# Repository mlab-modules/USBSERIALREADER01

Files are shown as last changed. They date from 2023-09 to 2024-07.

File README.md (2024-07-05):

# USBSDREADER01 - USB to SD Card Reader Module

## Overview
This module is designed to interface USB devices with SD cards, utilizing the MAX14502AETL integrated circuit. The MAX14502AETL supports both full-speed USB communication (12Mbps) for bridget devices and Hi-Speed USB communication (480Mbps) as SDcard reader, providing a versatile solution for various USB to SD card reading applications.

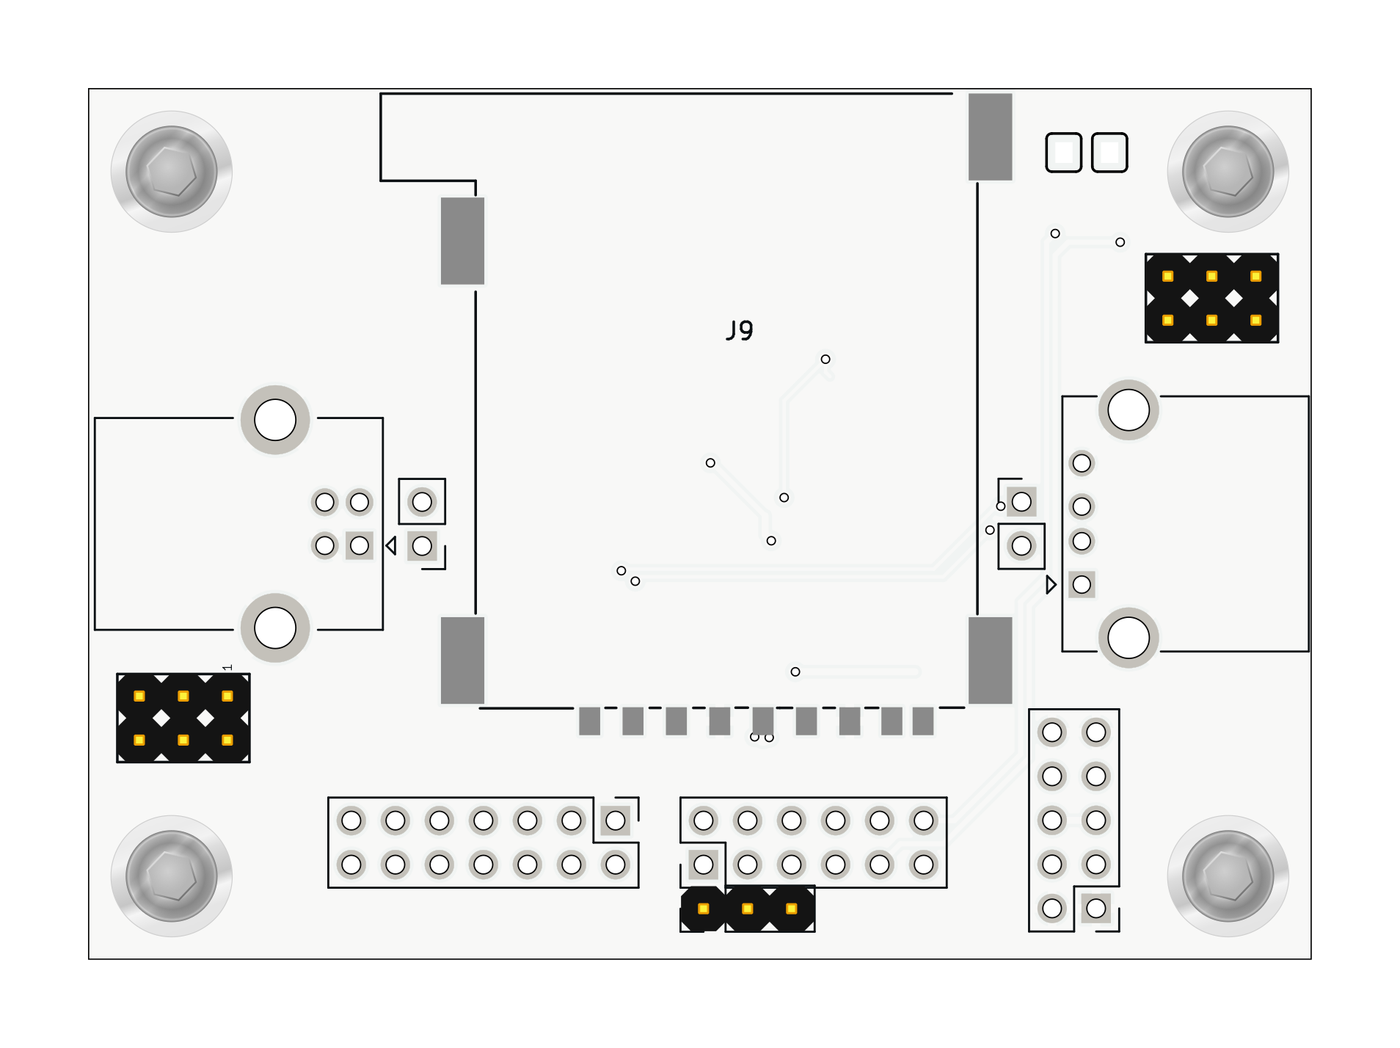
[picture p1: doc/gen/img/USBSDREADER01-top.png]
USBSDREADER01

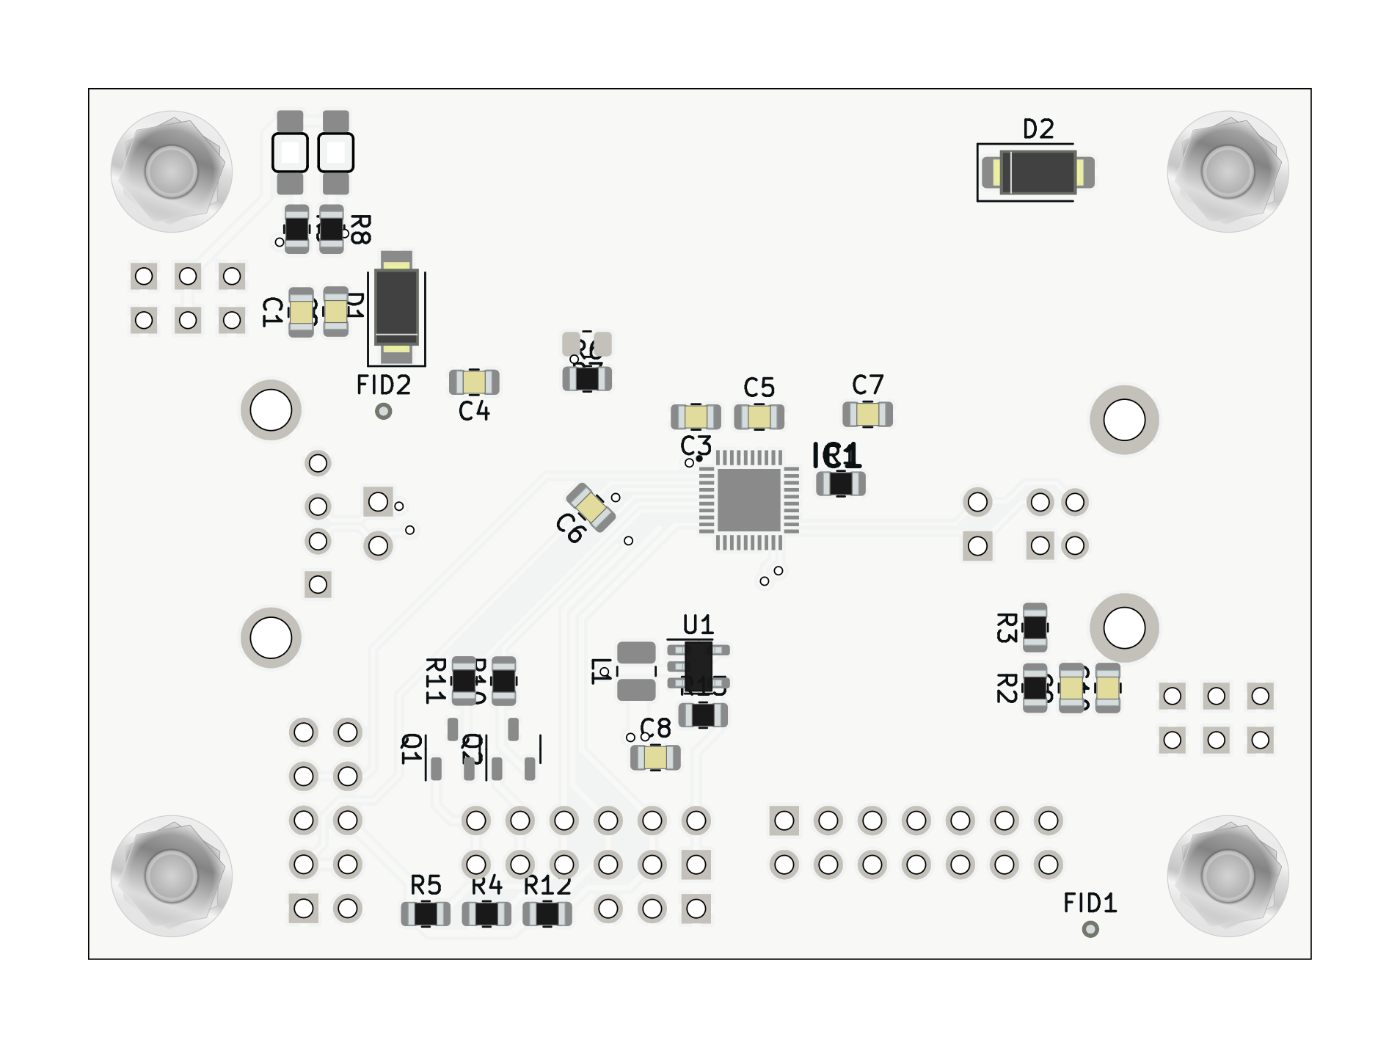
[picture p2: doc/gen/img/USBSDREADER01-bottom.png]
USBSDREADER01


## Features
- **USB 2.0 Hi-Speed and Full-Speed Compliant**
- **Supports SDHC Cards**
- **Internal Hi-Speed USB SD Card Reader**
- **On-Chip Termination and Pullup Resistors**
- **Internal SD Switches for Multiplexing Two SD Cards**
- **Clock Input Frequencies: 26MHz, 19.2MHz, 13MHz, 12MHz**
- **Low-Amplitude TCXO Signal Compatibility**
- **No Power-Supply Sequencing Required**
- **1.8V to 3.3V I/O Host Microprocessor Compatibility**
- **Simple GPIO Control Mode**
- **I2C Control for Multiple Configuration Options**
- **Power-On Reset/Brown-Out Reset**

## Technical Specifications
- **Supply Voltage (VCC):** 2.4V to 3.6V
- **Logic Interface Supply Voltage (VIO):** 1.5V to 3.6V
- **USB Supply Voltage (VTM):** 2.91V to 3.4V
- **Operating Temperature Range:** -40°C to +85°C
- **Package:** 40-pin TQFN

## Pin Description
- **I2C_SEL:** I2C Select Input
- **SCL:** I2C Serial-Clock Input
- **SDA:** I2C Serial-Data I/O
- **ADD:** I2C Address Selection Input
- **BERR/INT:** Card Reader Error/Interrupt Output
- **BUSY:** Busy Output
- **MODE:** Card Reader/Pass Thru Mode Select Input
- **RST:** Reset Input
- **FREF:** Frequency Input (12MHz/13MHz/19.2MHz/26MHz)

## Schematic
USB to SD Card Reader Schematic

## Applications
- Data loggers
- Cameras
- Flight computers

## Installation and Usage
1. **Power Supply:**
   - Connect the power supply to the VCC and GND pins.
   - Ensure the supply voltage is within the specified range (2.4V to 3.6V).

2. **USB Connection:**
   - Connect the USB data lines (D+ and D-) to the corresponding pins on the module.
   - Use the USB_B and USB_A connectors for input and output respectively.

3. **SD Card Connection:**
   - Connect the SD card signals (CMD, CLK, DAT0-3) to the corresponding pins on the module.
   - Ensure proper insertion and alignment of the SD card.

4. **I2C Configuration:**
   - If I2C control is needed, connect the I2C_SEL, SCL, and SDA pins appropriately.
   - Configure the I2C address using the ADD pin.

5. **Operation Modes:**
   - Select Pass Thru or Card Reader mode using the MODE pin.
   - Reset the device using the RST pin if necessary.

For detailed electrical characteristics and operational guidance, refer to the [MAX14502AETL Datasheet](./doc/datasheet/Maxim_Integrated-MAX14502AETL+-datasheet.pdf).

## Support
For further assistance, visit [MLAB](https://www.mlab.cz/) or contact our support team at support@mlab.cz.

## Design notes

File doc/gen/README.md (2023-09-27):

# PCB

Board size: 70.61x50.29 mm (2.78x1.98 inches)

- This is the size of the rectangle that contains the board
- Thickness: 1.6 mm (63 mils)
- Material: FR4
- Finish: HAL
- Layers: 2
- Copper thickness: 35 µm

Solder mask: TOP / BOTTOM

- Color: Green

Silk screen: TOP / BOTTOM

- Color: White

# Important sizes

Clearance: 0.2 mm (8 mils)

Track width: 0.2 mm (8 mils)

- By design rules: 0.2 mm (8 mils)

Drill: 0.5 mm (20 mils)

- Vias: 0.5 mm (20 mils) [Design: 0.4 mm (16 mils)]
- Pads: 1.0 mm (39 mils)
- The above values are real drill sizes, they add 0.1 mm (4 mils) to plated holes (PTH)

Via: 0.8/0.4 mm (31/16 mils)

- By design rules: 0.4/0.3 mm (16/12 mils)
- Micro via: yes [0.2/0.1 mm (8/4 mils)]
- Buried/blind via: yes
- Total: 13 (thru: 13 buried/blind: 0 micro: 0)

Outer Annular Ring: 0.15 mm (6 mils)

- By design rules: 0.26 mm (10 mils)

Eurocircuits class: 4B
- Using min drill 0.5 mm for an OAR of 0.15 mm

# General stats

Components count: (SMD/THT)

- Top: 1/14 (SMD + THT)
- Bottom: 34/0 (SMD)

Defined tracks:

- 0.2 mm (8 mils)
- 0.3 mm (12 mils)
- 0.4 mm (16 mils)
- 0.5 mm (20 mils)
- 1.0 mm (39 mils)

Used tracks:

- 0.2 mm (8 mils) (82) defined: yes
- 0.3 mm (12 mils) (62) defined: yes
- 0.4 mm (16 mils) (34) defined: yes
- 1.0 mm (39 mils) (4) defined: yes

Defined vias:

Used vias:

- 0.8/0.4 mm (31/16 mils) (Count: 13, Aspect: 2.0 A) defined: no

Holes (excluding vias):

- 0.89 mm (35 mils) (12)
- 0.92 mm (36 mils) (4)
- 0.95 mm (37 mils) (4)
- 1.0 mm (39 mils) (43)
- 2.3 mm (91 mils) (4)
- 3.0 mm (118 mils) (4)

Oval holes:

Drill tools (including vias and computing adjusts and rounding):

- 0.5 mm (20 mils) (13)
- 1.0 mm (39 mils) (16)
- 1.05 mm (41 mils) (4)
- 1.1 mm (43 mils) (43)
- 2.4 mm (94 mils) (4)
- 3.1 mm (122 mils) (4)

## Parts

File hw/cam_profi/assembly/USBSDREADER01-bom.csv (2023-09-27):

Component | Description | Part | References | Value | Footprint | Quantity Per PCB | Datasheet | ust_id | height | manufacturer_name | manufacturer_part_number | sim.device | sim.pins | sim.type
1 |  | C_Small-Device-ISM02A-rescue | C2C10 | 100nF | C_0805_2012Metric | 2 |  | 5c70984812875079b91f8bf2
2 |  | C_Small-Device-ISM02A-rescue | C1C9 | 10uF | C_0805_2012Metric | 2 |  | 5c70984812875079b91f8bbe
3 | Unpolarized capacitor, small symbol | C_Small | C8 | 10uF | C_0805_2012Metric | 1 | ~
4 | Unpolarized capacitor, small symbol | C_Small | C3C4C5C6C7 | C_Small | C_0805_2012Metric | 5 | ~
5 |  | D_ZENER-MLAB_D | D1D2 | BZV55C-5,6V | D_SMA | 2 |  | 5c70984512875079b91f88b2
6 | Light emitting diode | LED | D3D4 | LED | LED_1206_mill | 2 | ~
7 | Hi-Speed USB-to-SD Card Readers with Bypass | MAX14502AETL+ | IC1 | MAX14502AETL+ | QFN40P500X500X80-41N | 1 | https://datasheet.octopart.com/MAX14502AETL%2B-Dallas-Semiconductor-datasheet-13718882.pdf |  | 0.8 | Analog Devices | MAX14502AETL+
8 | 2x03 2.54 mm pitch header, 2 pins next to each other are connected | HEADER_2x03_PARALLEL | J1 | 3.3V | Straight_2x03 | 1
9 | 1x03 2.54 mm pitch header | HEADER_1x03 | J8 | HEADER_1x02 | PinHeader_1x03_P2.54mm_Vertical | 1
10 | 2x06 2.54 mm pitch header, 2 pins next to each other are connected | HEADER_2x06_PARALLEL | J7 | HEADER_2x04_PARALLEL | PinHeader_2x06_P2.54mm_Vertical | 1
11 | 2x05 2.54 mm pitch header, 2 pins next to each other are connected | HEADER_2x05_PARALLEL | J6 | HEADER_2x05_PARALLEL | PinHeader_2x05_P2.54mm_Vertical | 1
12 | 2x07 2.54 mm pitch header, 2 pins next to each other are connected | HEADER_2x07_PARALLEL | J5 | HEADER_2x07_PARALLEL | PinHeader_2x07_P2.54mm_Vertical | 1
13 |  | SD_Card-FPS009-4200-0 | J9 | SD_Card-FPS009-4200-0 | FPS009-4200-0 | 1
14 | USB Type A connector | USB_A | J3 | USB_A | USB_A_CONNFLY_DS1095-WNR0 | 1 | ~
15 | USB Type B connector | USB_B | J2 | USB_B | USB_B_Lumberg_2411_02_Horizontal | 1 | ~
16 | 2x03 2.54 mm pitch header, 2 pins next to each other are connected | HEADER_2x03_PARALLEL | J4 | VBUS | Straight_2x03 | 1
17 | Inductor, small symbol | L_Small | L1 | 1uH | L_1008_2520Metric | 1 | ~
18 | Bipolar transistor symbol for simulation only, substrate tied to the emitter | NPN | Q1Q2 | NPN | SOT-23-3 | 2 | ~ |  |  |  |  | NPN | 1=C 2=B 3=E | GUMMELPOON
19 | Resistor, small symbol | R_Small | R1 | 6.19k | R_0805_2012Metric | 1 | ~
20 | Resistor, small symbol | R_Small | R2R3R4R5R12R13 | 10k | R_0805_2012Metric | 6 | ~
21 | Resistor, small symbol | R_Small | R6R8R9R10R11 | R_Small | R_0805_2012Metric | 5 | ~
22 |  | TS5A4594 | U1 | TS5A4594 | SOT-23-5 | 1

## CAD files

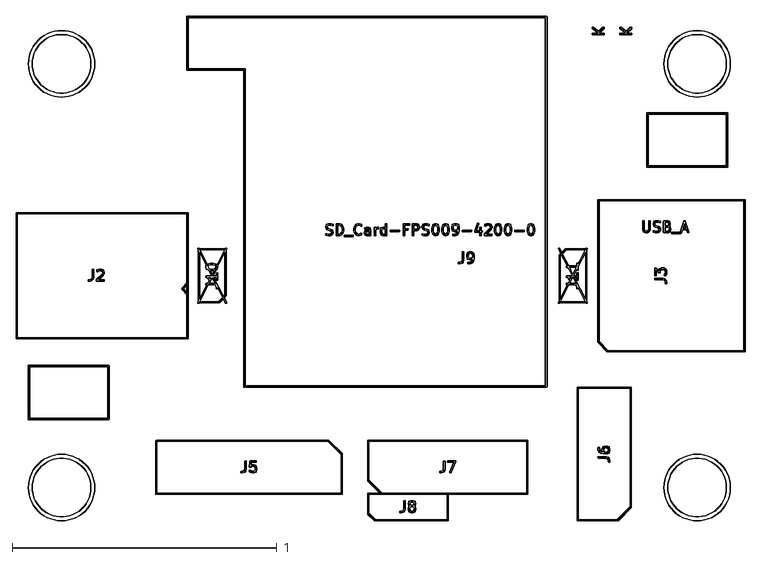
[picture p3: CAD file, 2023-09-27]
doc/gen/dxf/USBSDREADER01-F_Fab.dxf
2.75 x 1.91

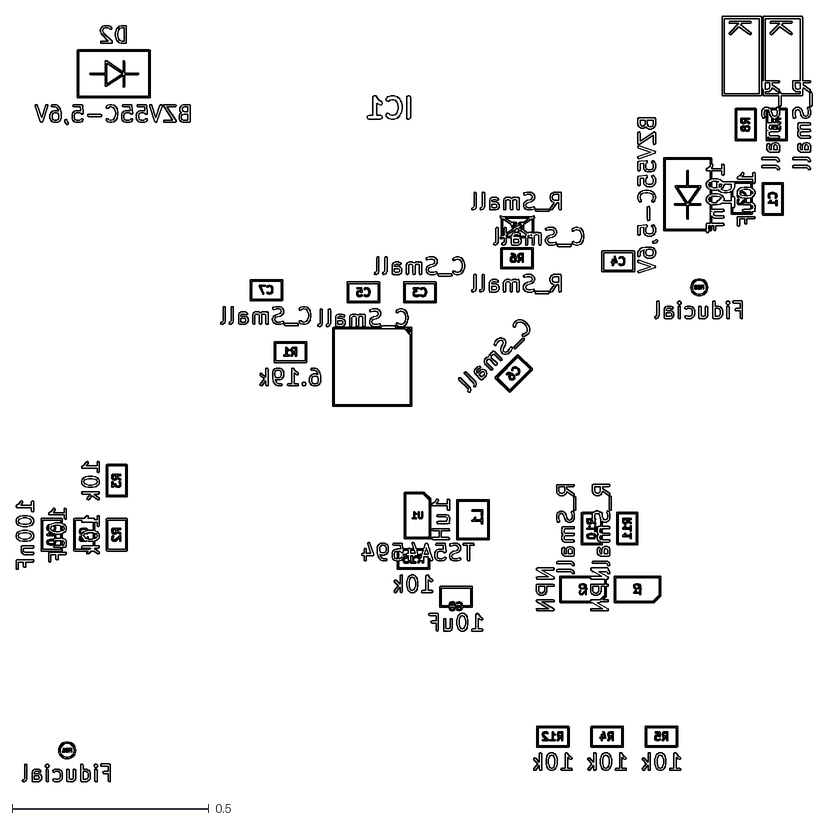
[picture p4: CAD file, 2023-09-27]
doc/gen/dxf/USBSDREADER01-B_Fab.dxf
2.02 x 1.95

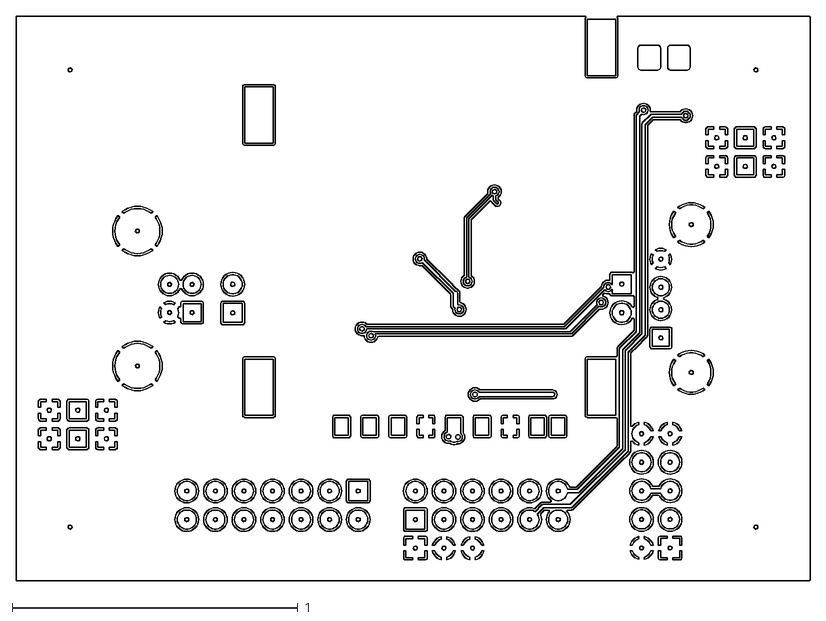
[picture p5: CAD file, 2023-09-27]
doc/gen/dxf/USBSDREADER01-F_Cu.dxf
2.78 x 1.98

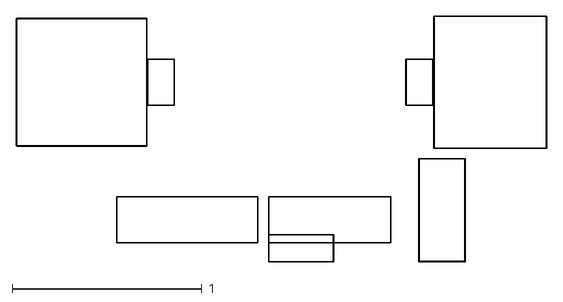
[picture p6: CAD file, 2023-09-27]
doc/gen/dxf/USBSDREADER01-F_Courtyard.dxf
2.79 x 1.29

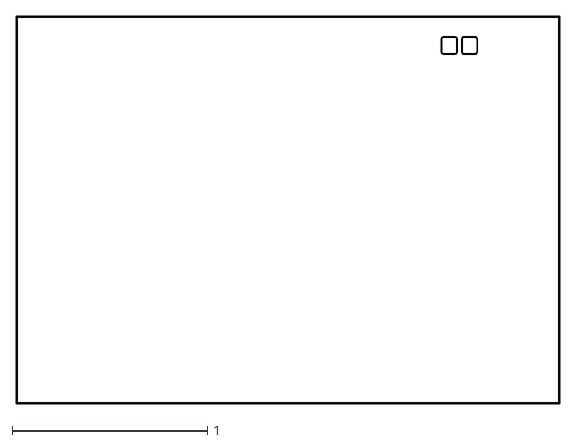
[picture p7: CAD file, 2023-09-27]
doc/gen/dxf/USBSDREADER01-Edge_Cuts.dxf
2.79 x 1.99

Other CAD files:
doc/gen/dxf/USBSDREADER01-User_8.dxf
doc/gen/dxf/USBSDREADER01-User_3.dxf
doc/gen/dxf/USBSDREADER01-User_Comments.dxf
doc/gen/dxf/USBSDREADER01-User_2.dxf
doc/gen/dxf/USBSDREADER01-User_Eco1.dxf
doc/gen/dxf/USBSDREADER01-User_6.dxf
doc/gen/dxf/USBSDREADER01-Margin.dxf
doc/gen/dxf/USBSDREADER01-User_4.dxf
doc/gen/dxf/USBSDREADER01-F_Adhesive.dxf
doc/gen/dxf/USBSDREADER01-User_9.dxf
doc/gen/dxf/USBSDREADER01-User_7.dxf
doc/gen/dxf/USBSDREADER01-User_Eco2.dxf
doc/gen/dxf/USBSDREADER01-B_Adhesive.dxf
doc/gen/dxf/USBSDREADER01-B_Courtyard.dxf
doc/gen/dxf/USBSDREADER01-B_Cu.dxf
doc/gen/dxf/USBSDREADER01-B_Mask.dxf
doc/gen/dxf/USBSDREADER01-B_Paste.dxf
doc/gen/dxf/USBSDREADER01-B_Silkscreen.dxf
doc/gen/dxf/USBSDREADER01-F_Mask.dxf
doc/gen/dxf/USBSDREADER01-F_Paste.dxf
doc/gen/dxf/USBSDREADER01-F_Silkscreen.dxf
doc/gen/dxf/USBSDREADER01-User_1.dxf
doc/gen/dxf/USBSDREADER01-User_5.dxf
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

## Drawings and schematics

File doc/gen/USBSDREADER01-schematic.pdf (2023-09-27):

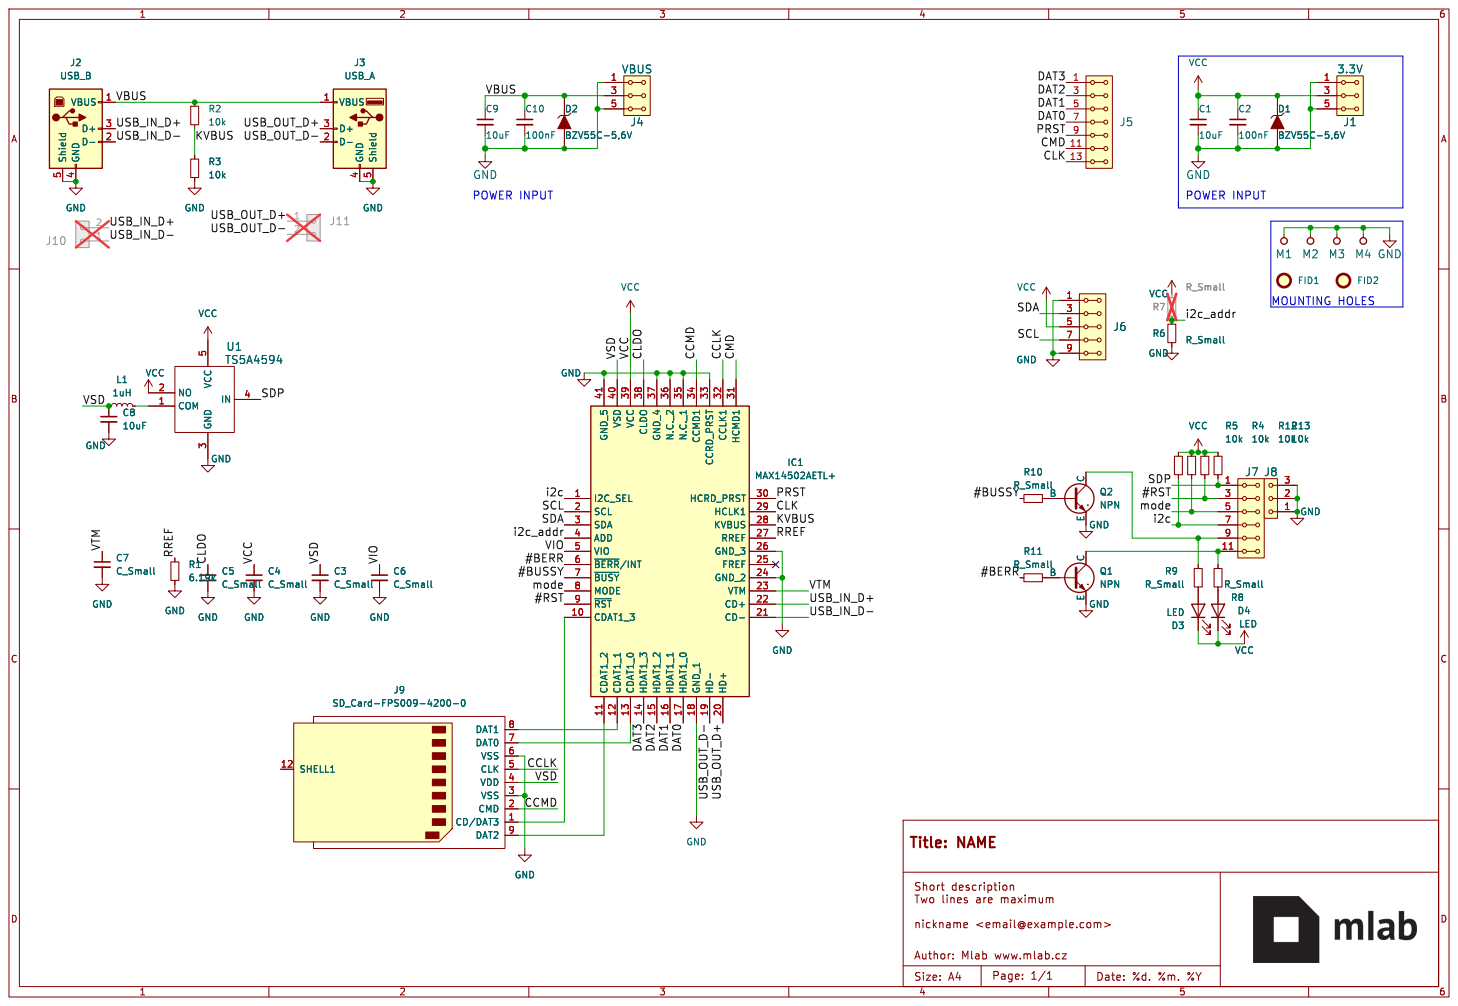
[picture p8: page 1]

POWER INPUT MOUNTING HOLES

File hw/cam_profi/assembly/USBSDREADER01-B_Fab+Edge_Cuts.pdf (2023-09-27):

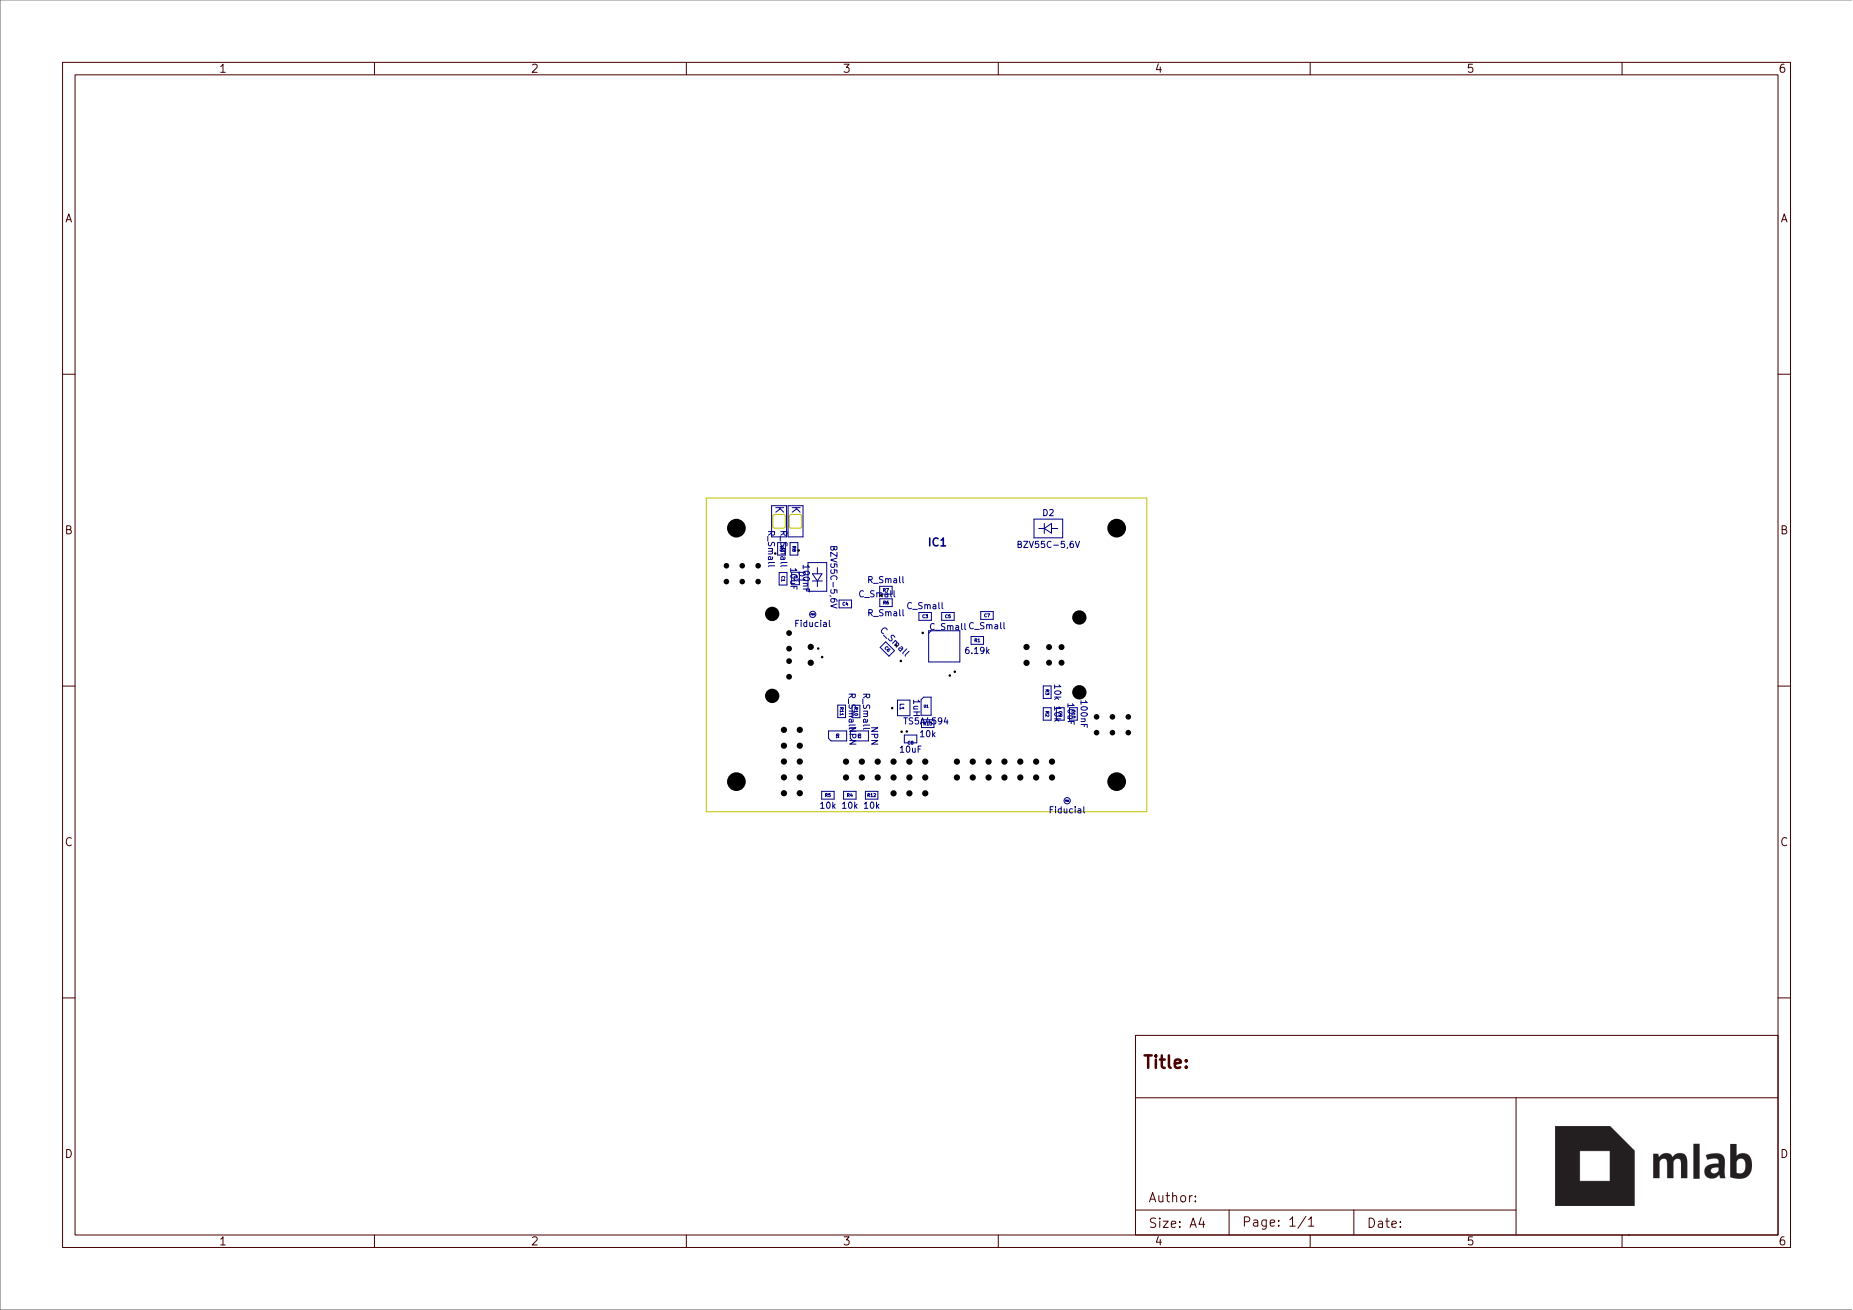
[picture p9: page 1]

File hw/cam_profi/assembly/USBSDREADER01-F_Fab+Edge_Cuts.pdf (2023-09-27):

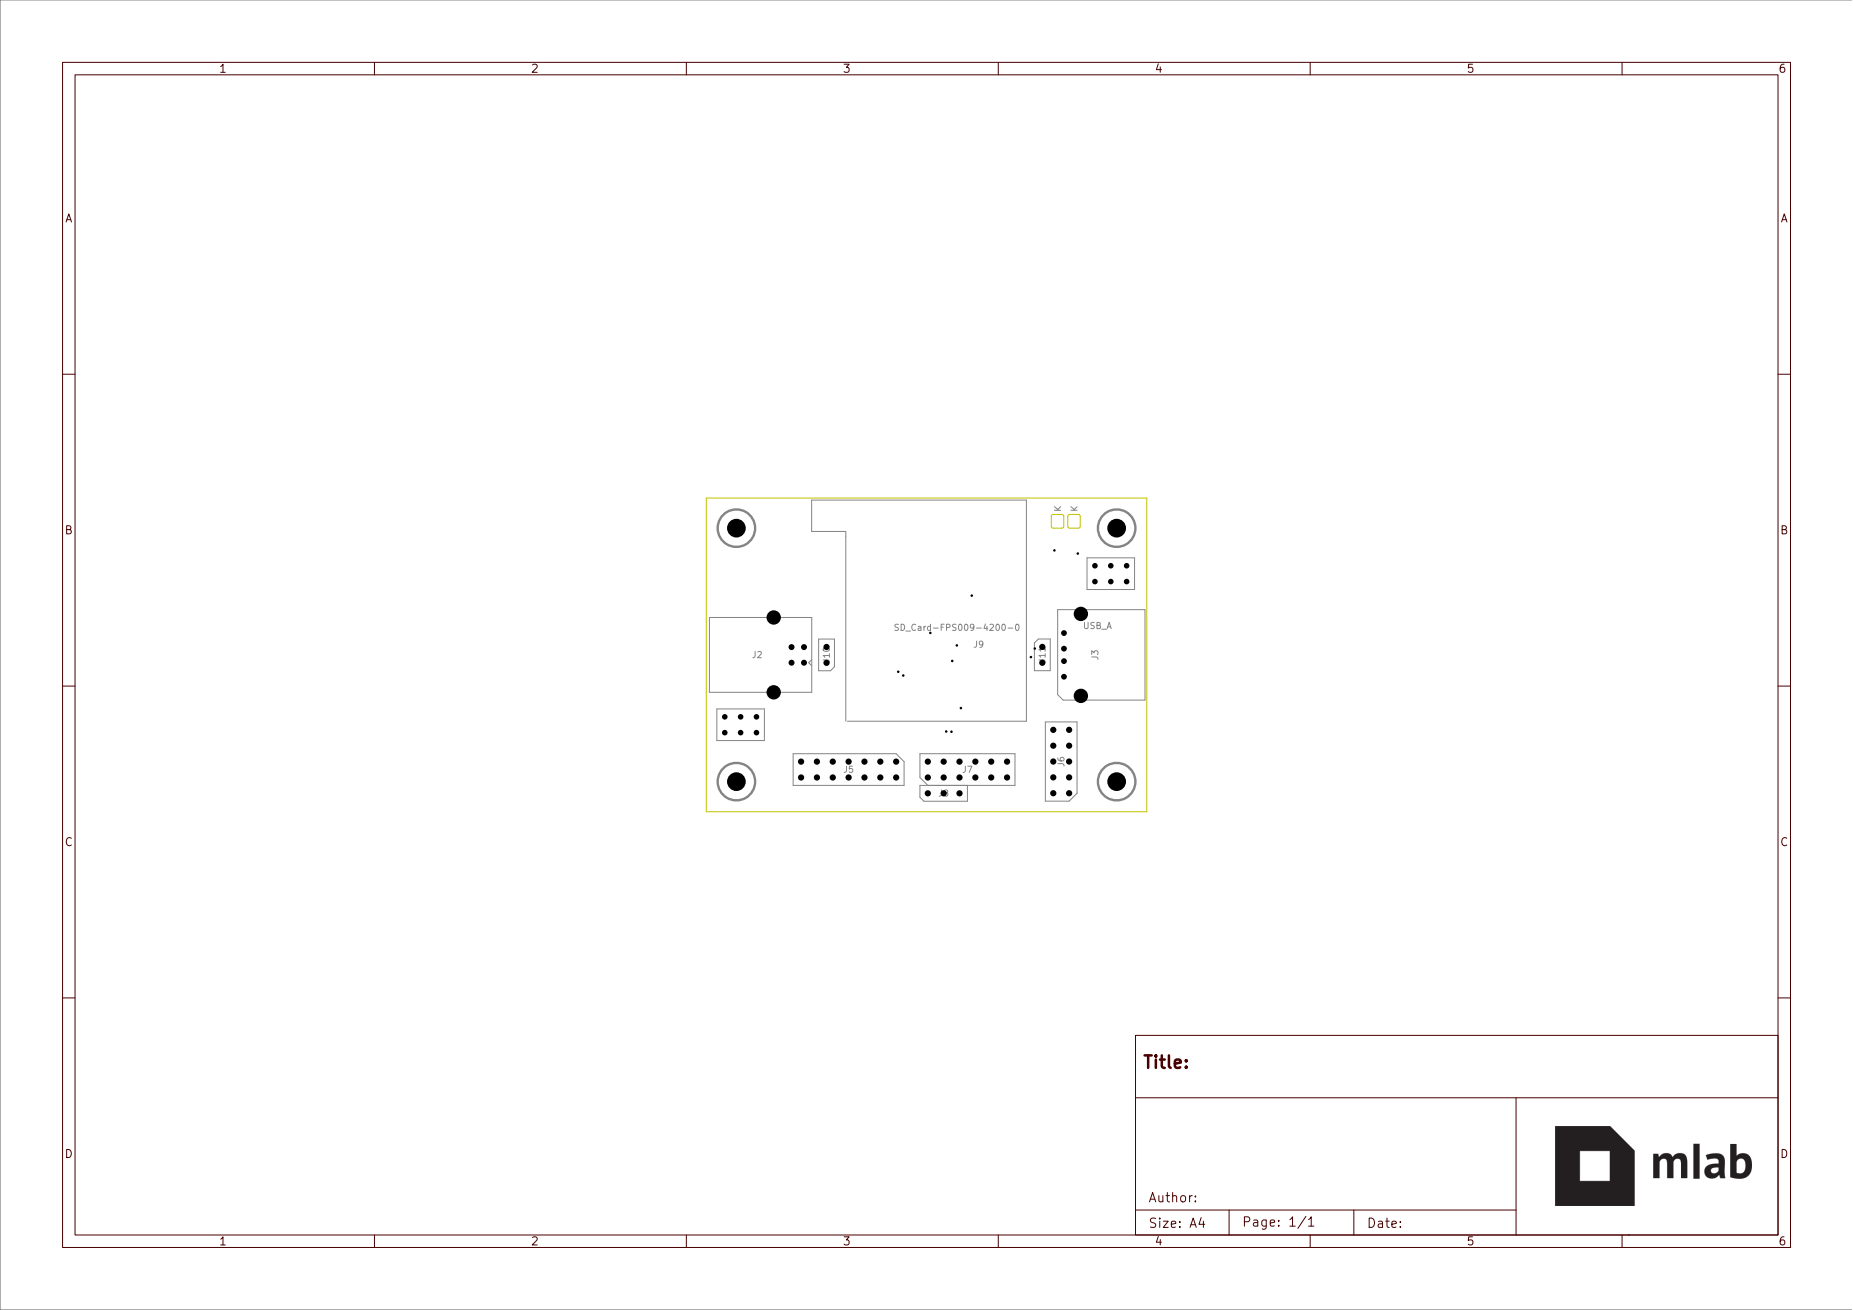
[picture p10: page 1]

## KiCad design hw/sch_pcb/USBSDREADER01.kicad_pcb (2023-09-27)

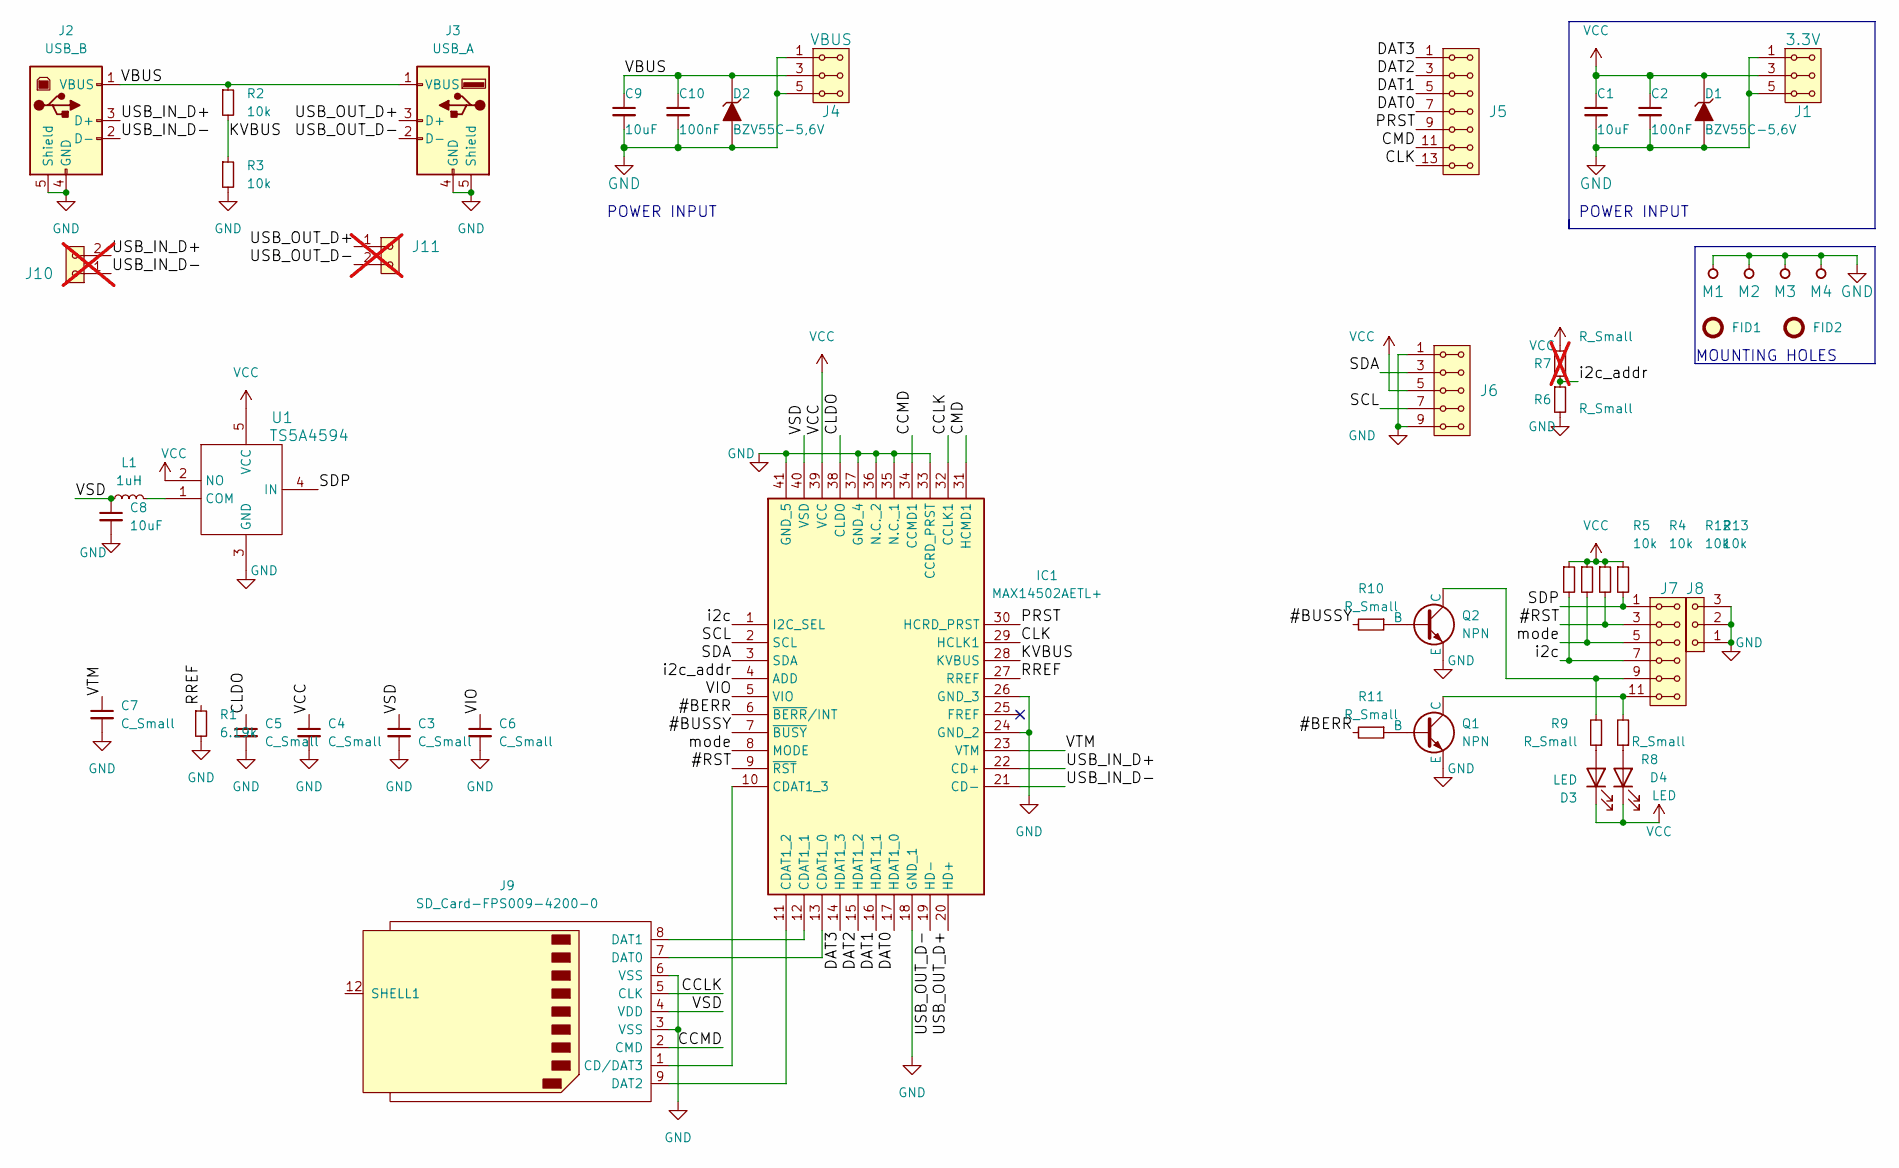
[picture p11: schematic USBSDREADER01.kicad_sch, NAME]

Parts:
C1, C8, C9: 10uF; C_0805_2012Metric
C2, C10: 100nF; C_0805_2012Metric
C3, C4, C5, C6, C7: C_Small; C_0805_2012Metric
D1, D2: BZV55C-5,6V; D_SMA
D3, D4: LED; LED_1206_mill
FID1, FID2: Fiducial; Fiducial_0.5mm_Mask1mm
IC1: MAX14502AETL+; QFN40P500X500X80-41N; Manufacturer_Part_Number MAX14502AETL+
J1: 3.3V; Straight_2x03
J2: USB_B; USB_B_Lumberg_2411_02_Horizontal
J3: USB_A; USB_A_CONNFLY_DS1095-WNR0
J4: VBUS; Straight_2x03
J5: HEADER_2x07_PARALLEL; PinHeader_2x07_P2.54mm_Vertical
J6: HEADER_2x05_PARALLEL; PinHeader_2x05_P2.54mm_Vertical
J7: HEADER_2x04_PARALLEL; PinHeader_2x06_P2.54mm_Vertical
J8: HEADER_1x02; PinHeader_1x03_P2.54mm_Vertical
J9: SD_Card-FPS009-4200-0; FPS009-4200-0
J10, J11: HEADER_1x02; PinHeader_1x02_P2.54mm_Vertical; not fitted
L1: 1uH; L_1008_2520Metric
M1, M2: HOLE M3; MountingHole_3mm
M3, M4: HOLE; MountingHole_3mm
Q1, Q2: NPN; SOT-23-3
R1: 6.19k; R_0805_2012Metric
R2, R3, R4, R5, R12, R13: 10k; R_0805_2012Metric
R6, R8, R9, R10, R11: R_Small; R_0805_2012Metric
R7: R_Small; R_0805_2012Metric; not fitted
U1: TS5A4594; SOT-23-5

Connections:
/#BERR: IC1.6 (~BERR/INT), R11.2
/#BUSSY: IC1.7 (~BUSY), R10.2
/#RST: IC1.9 (~RST), J7.3, J7.4, R12.2
/CCLK: IC1.32 (CCLK1), J9.5 (CLK)
/CCMD: IC1.34 (CCMD1), J9.2 (CMD)
/CLDO: C5.1, IC1.38 (CLDO)
/CLK: IC1.29 (HCLK1), J5.13, J5.14
/CMD: IC1.31 (HCMD1), J5.11, J5.12
/DAT0: IC1.17 (HDAT1_0), J5.7, J5.8
/DAT1: IC1.16 (HDAT1_1), J5.5, J5.6
/DAT2: IC1.15 (HDAT1_2), J5.3, J5.4
/DAT3: IC1.14 (HDAT1_3), J5.1, J5.2
/KVBUS: IC1.28 (KVBUS), R2.2, R3.1
/PRST: IC1.30 (HCRD_PRST), J5.9, J5.10
/RREF: IC1.27 (RREF), R1.1
/SCL: IC1.2 (SCL), J6.7, J6.8
/SDA: IC1.3 (SDA), J6.3, J6.4
/SDP: J7.1, J7.2, R13.2, U1.4 (IN)
/USB_IN_D+: IC1.22 (CD+), J2.3 (D+), J10.2
/USB_IN_D-: IC1.21 (CD-), J2.2 (D-), J10.1
/USB_OUT_D+: IC1.20 (HD+), J3.3 (D+), J11.1
/USB_OUT_D-: IC1.19 (HD-), J3.2 (D-), J11.2
/VBUS: C9.1, C10.1, D2.1 (K), J2.1 (VBUS), J3.1 (VBUS), J4.3, J4.4, R2.1
/VIO: C6.1, IC1.5 (VIO)
/VSD: C3.1, C8.1, IC1.40 (VSD), J9.4 (VDD), L1.1
/VTM: C7.1, IC1.23 (VTM)
/i2c: IC1.1 (I2C_SEL), J7.7, J7.8, R5.2
/i2c_addr: IC1.4 (ADD), R6.1, R7.2
/mode: IC1.8 (MODE), J7.5, J7.6, R4.2
GND: C1.2, C2.2, C3.2, C4.2, C5.2, C6.2, C7.2, C8.2, C9.2, C10.2, D1.2 (A), D2.2 (A), IC1.18 (GND_1), IC1.24 (GND_2), IC1.26 (GND_3), IC1.33 (CCRD_PRST), IC1.35 (N.C._1), IC1.36 (N.C._2), IC1.37 (GND_4), IC1.41 (GND_5), J1.1, J1.2, J1.5, J1.6, J2.4 (GND), J2.5 (Shield), J3.4 (GND), J3.5 (Shield), J4.1, J4.2, J4.5, J4.6, J6.1, J6.2, J6.9, J6.10, J8.1, J8.2, J8.3, J9.3 (VSS), J9.6 (VSS), M1.1, M2.1, M3.1, M4.1, Q1.3 (E), Q2.3 (E), R1.2, R3.2, R6.2, U1.3 (GND)
unnamed: D3.2 (A), R9.1
unnamed: D4.2 (A), R8.1
unnamed: IC1.13 (CDAT1_0), J9.7 (DAT0)
unnamed: IC1.12 (CDAT1_1), J9.8 (DAT1)
unnamed: IC1.11 (CDAT1_2), J9.9 (DAT2)
unnamed: IC1.10 (CDAT1_3), J9.1 (CD/DAT3)
unnamed: Q1.2 (B), R11.1
unnamed: J7.11, J7.12, Q1.1 (C), R8.2
unnamed: Q2.2 (B), R10.1
unnamed: J7.9, J7.10, Q2.1 (C), R9.2
unnamed: L1.2, U1.1 (COM)
VCC: C1.1, C2.1, C4.1, D1.1 (K), D3.1 (K), D4.1 (K), IC1.39 (VCC), J1.3, J1.4, J6.5, J6.6, R4.1, R5.1, R7.1, R12.1, R13.1, U1.2 (NO), U1.5 (VCC)

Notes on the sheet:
POWER INPUT
MOUNTING HOLES

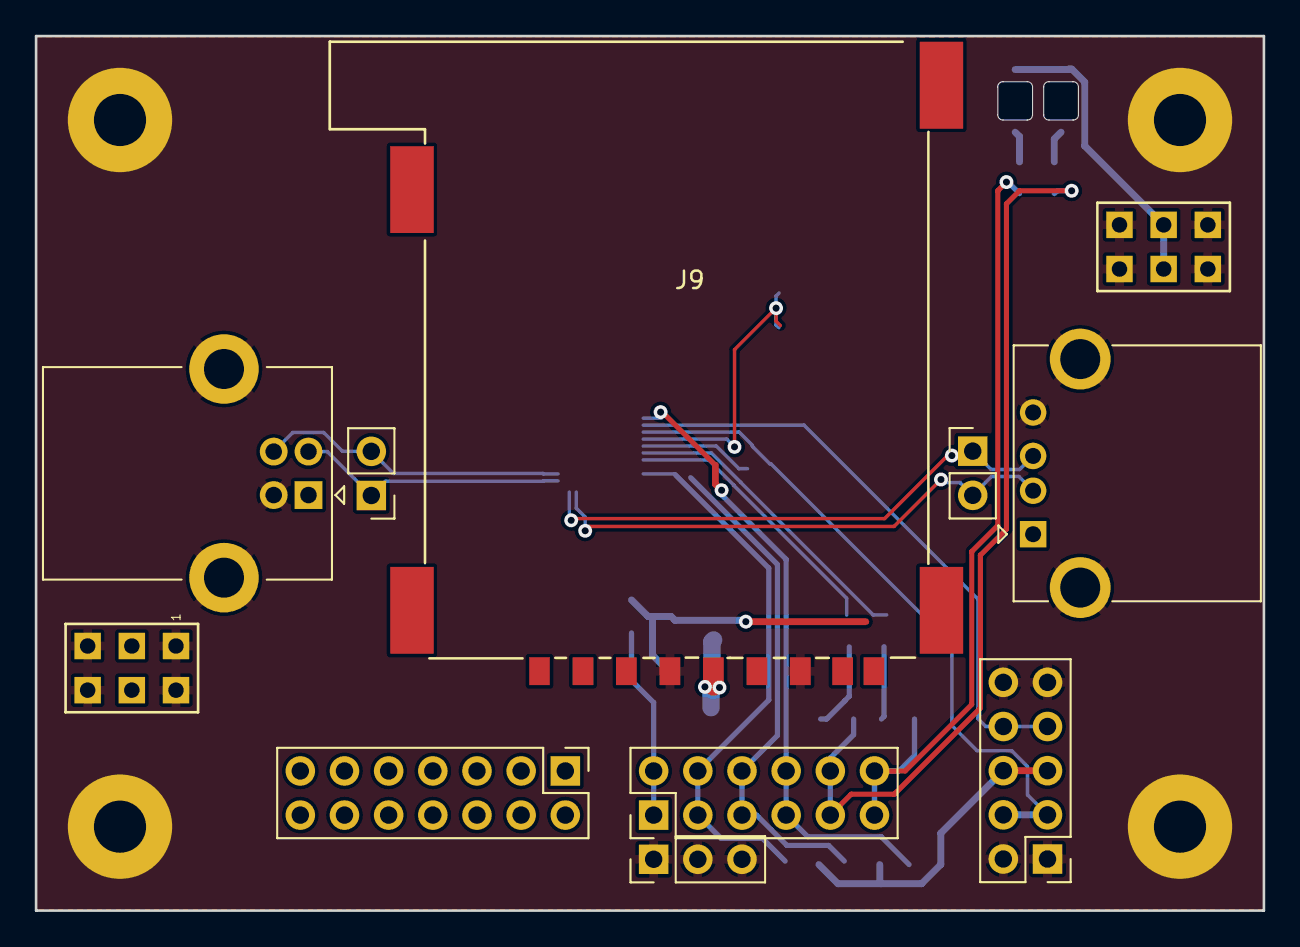
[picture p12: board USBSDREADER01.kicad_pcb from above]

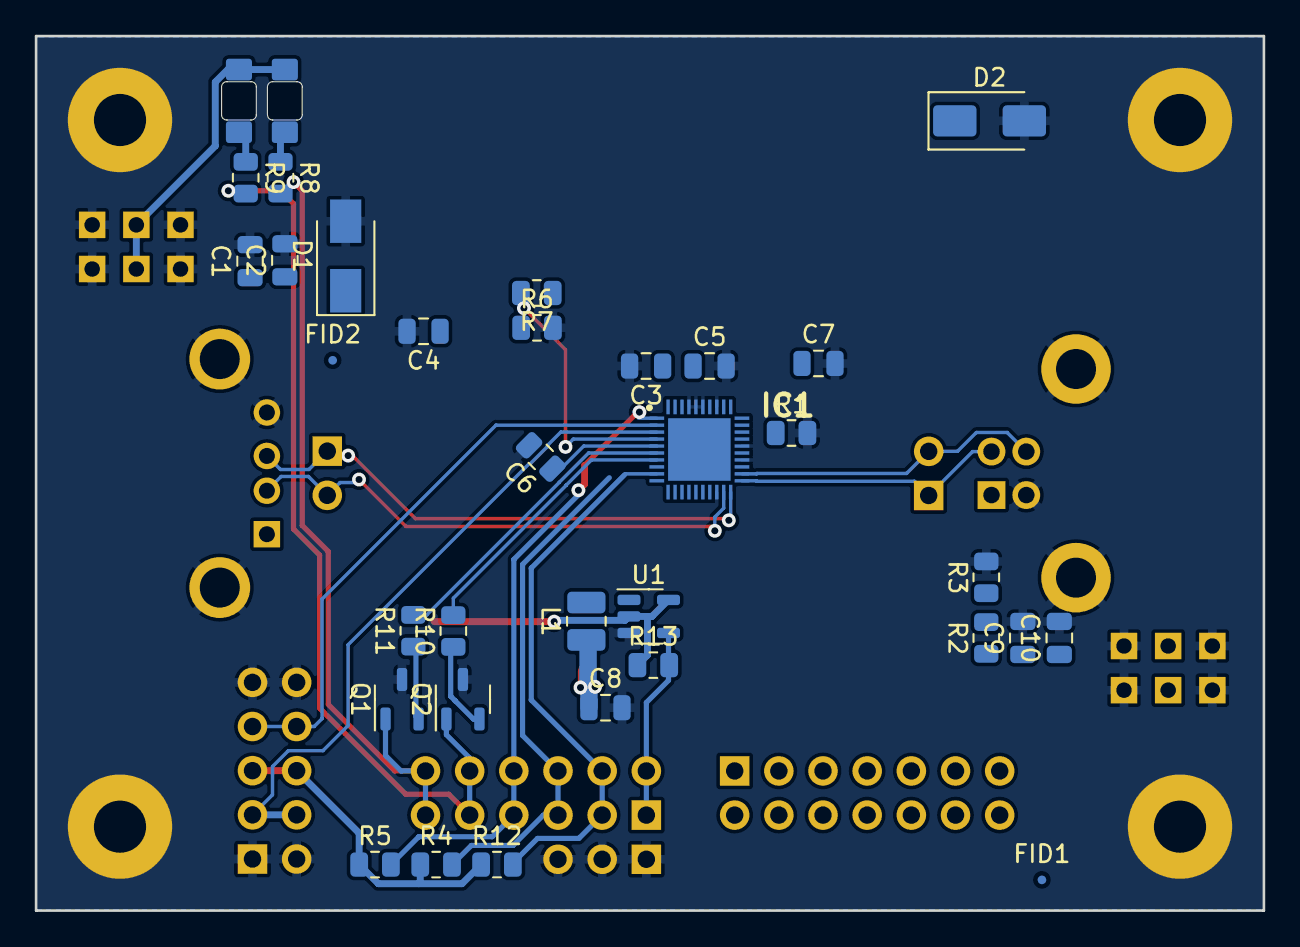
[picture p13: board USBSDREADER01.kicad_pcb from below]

Board: 2 copper layers, 70.6 x 50.3 mm, 49 parts (34 on the bottom side), 42 nets.

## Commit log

2023-09-27 Update actions products
    [USBSDREADER01-B_Adhesive.dxf, USBSDREADER01-B_Courtyard.dxf, USBSDREADER01-B_Cu.dxf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]
2024-07-05 Update documentation.
    [USBSDREADER01.kicad_sch]
